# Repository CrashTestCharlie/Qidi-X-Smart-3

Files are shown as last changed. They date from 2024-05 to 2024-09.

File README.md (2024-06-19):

# Qidi X-Smart 3

- [Images](#images)
- [Mods](#mods)
- [Software/Firmware](#softwarefirmware)

------------------------------------------------------------------------

## Images

### Electronics Bay

Images:

- [Overview](images/electronics-bay.jpg)
- [Mainboard](images/mainboard-01.jpg)
- [Mainboard closeup](images/mainboard-02.jpg)
- [Mainboard ports](images/mainboard-ports.jpg)
- [Mainboard pinout](images/mainboard-pins.png)
- [Power supply](images/power-supply.jpg)
- [Power switch](images/power-switch.jpg)
- [Toolhead pinout](images/A-4.V1.2_003.PIN.pdf) (PDF)

#### Notes

Initial inspection found the USB extension cable not fully seated in the
top USB 2.0 port.

## Mods

Mods found in this repository:

- [Camera mod](./camera-mount/README.md): add a webcam
- [Config mod](./configs/README.md): fixing Qidi’s copy/paste errors and
  adding functionality.
- [Exhaust filter mod](./exhaust-filter/README.md): Add charcoal
  filtering to the exhaust fan.
- [Fan mod](./fan-mod/README.md): control the mainboard fan with
  Klipper, instead of always on.
- [Heater mod](./heater-mod/README.md): active chamber heater mod
- [Thermistor mount](./thermistor-mount/README.md): a mount for the
  thermistor used in the header mod.

## Software/Firmware

Software/Firmware versions as shipped:

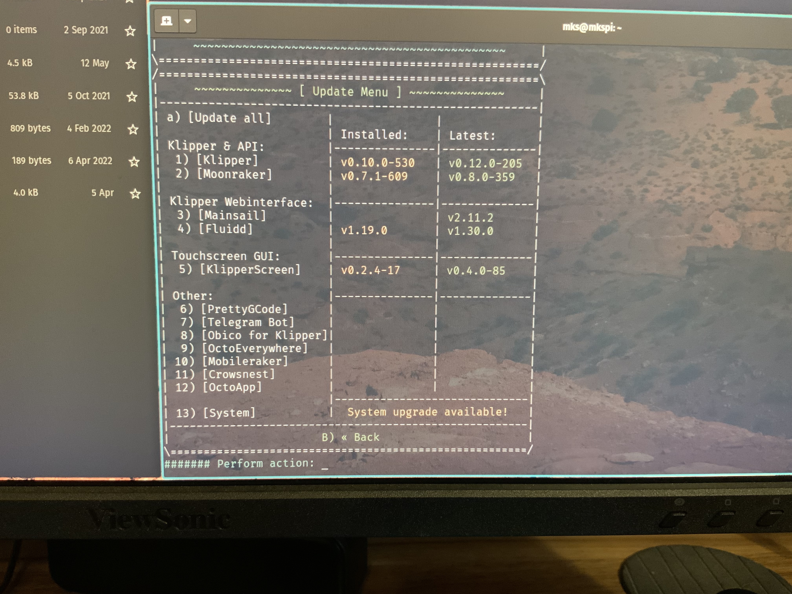
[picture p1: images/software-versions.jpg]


Default ssh login: mks/makerbase

Armbian OS info:

    mks@mkspi:~$ cat /etc/armbian-image-release
    # PLEASE DO NOT EDIT THIS FILE
    BOARD=mkspi
    BOARD_NAME="mkspi"
    BOARDFAMILY=rockchip64
    BUILD_REPOSITORY_URL=https://github.com/armbian/build.git
    BUILD_REPOSITORY_COMMIT=ed589b248-dirty
    VERSION=22.05.0-trunk
    LINUXFAMILY=rockchip64
    ARCH=arm64
    IMAGE_TYPE=user-built
    BOARD_TYPE=conf
    INITRD_ARCH=arm64
    KERNEL_IMAGE_TYPE=Image
    IMAGE_UUID=16031aaf-8c15-492e-97bf-3453cab5322c

    mks@mkspi:~$ cat /etc/armbian-release
    # PLEASE DO NOT EDIT THIS FILE
    BOARD=mkspi
    BOARD_NAME="mkspi"
    BOARDFAMILY=rockchip64
    BUILD_REPOSITORY_URL=https://github.com/armbian/build.git
    BUILD_REPOSITORY_COMMIT=ed589b248-dirty
    VERSION=22.05.0-trunk
    LINUXFAMILY=rockchip64
    ARCH=arm64
    IMAGE_TYPE=user-built
    BOARD_TYPE=conf
    INITRD_ARCH=arm64
    KERNEL_IMAGE_TYPE=Image
    BRANCH=edge

    mks@mkspi:~$ cat /etc/armbian-distribution-status
    bullseye=supported
    impish=csc
    xenial=eos
    stretch=eos
    buster=supported
    hirsute=supported
    sid=csc
    jammy=csc
    focal=supported
    bionic=csc

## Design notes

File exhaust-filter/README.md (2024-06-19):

# X-Smart 3 Exhaust Fan Filter

An activated charcoal filter for the exhaust fan. The replacement fan
mount also includes a thermistor mount for monitoring chamber
temperature.

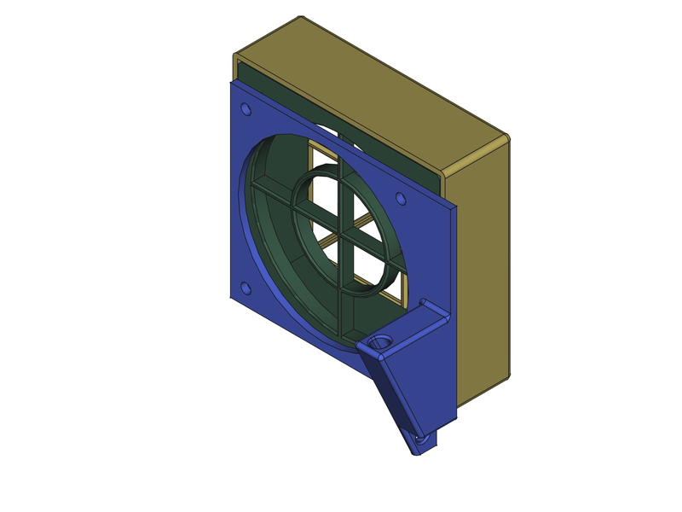
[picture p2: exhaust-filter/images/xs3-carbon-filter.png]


## Parts needed

- Printed parts from the [STLs directory](./STLs/)
- 4 M3x4x5mm heat set inserts
- 4 M3x20mm cap screws
- Activated charcoal filter media, Amazon ASIN:
  [B09F6793ST](https://a.co/d/02k9A120). This package will make 40
  filter squares.

## Instructions

1.  Install heat set inserts into the `filter-base.stl` from the flat
    side.
2.  Remove the fan from the XS3.
3.  Re-install the fan.
    1.  The `fan-mount.stl` goes between the fan and the chamber wall.
    2.  Install the `filter-base.stl` with the arrow pointing up.
4.  Using the `filter-jig.stl` cut the filter media into 60x60mm
    squares.
5.  Install one or two filter squares into the `filter-base.stl`.
6.  Slide `filter-cover.stl` onto the `filter-base.stl` from the top.
    Make sure it clicks into place.

Enjoy your filtered exhaust.

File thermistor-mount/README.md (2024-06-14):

# Thermistor Mount

This is a mount for a chamber thermistor.

## Hardware needed

- 1 thermistor
- 4 M3x20mm cap screws
- 1 printed mount

The STL can be found in this directory,
[xs3-thermistor-mount.stl](./xs3-thermistor-mount.stl). Print as
imported.

The thermistor used can be found on amazon, [3950 NTC 100K Thermistor
Sensor (5 pack)](https://a.co/d/aC1xXPI).

## Tools needed

- 2.5mm hex wrench
- JST-XH terminals and crimpers (optional)

The terminals and crimpers are only needed if shortening the thermistor
leads.

# Installation

1.  Remove the chamber exhaust fan. The fan, fan grill, and nuts will be
    reused.
2.  Install the thermistor into the mount from the bottom.
3.  Using a M3x20mm screw, line up the fan and mount and insert the
    screw into the top right mounting hole.
4.  Loop the thermistor lead through the hook on the bottom of the
    mount.
5.  Install the grill and nut on the screw, but don’t tighten.
6.  Install the other three screws.
7.  Tighten all the screws, making sure the thermistor leads are still
    captured by the mount’s hook.
8.  Adjust the thermistor so the body is above the mount.
9.  Remove the two cable clips on the rear left side of the printer.
10. Route the thermistor lead through the clips.
11. Reattach the cable clips.
12. Route the thermistor lead through the hole in the center rear of the
    chamber floor. Make sure the leads run behind the bed cable.
13. Follow the directions for the [Chamber Heater
    Mod](../heater-mod/README.md) for connection and Klipper
    integration.

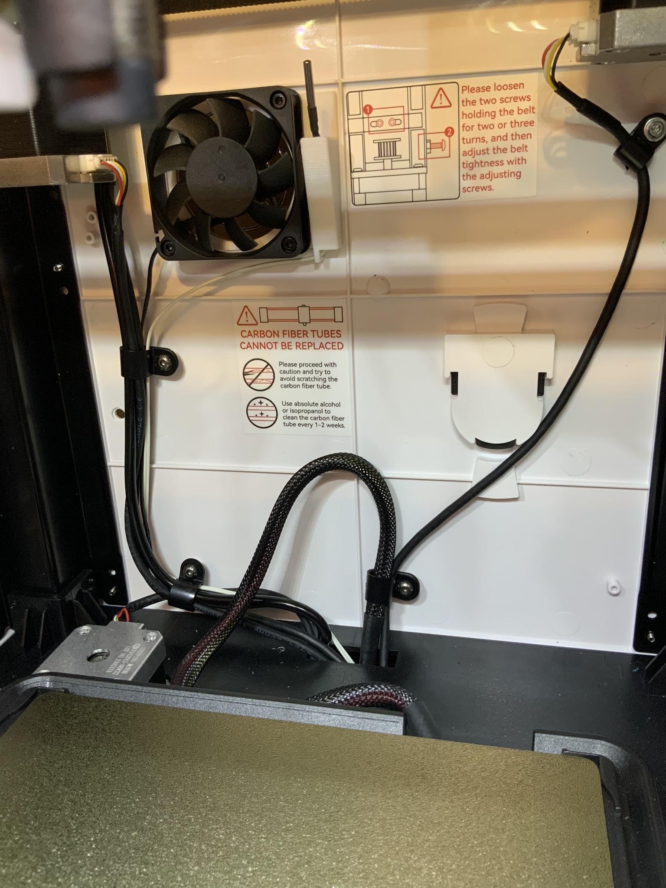
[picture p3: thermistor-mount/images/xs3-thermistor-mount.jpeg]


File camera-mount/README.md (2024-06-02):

# Camera Mount

While Qidi sells a camera, using a better camera makes for a better
result.





## The Mount

The mount is a printed base and lid that mounts on the right front
upright of the X-Smart 3 using existing mounting holes.



### Tools needed

- Heatset tool (soldering iron with heatset tips, or equivalent)
- 3mm hex wrench
- 2.5mm hex wrench
- Other screwdrivers as needed. (The only 2.5mm screws I could source
  locally were slotted drive.)

### Parts required

- Webcam module, [Innomaker 1080P USB2.0 UVC
  Camera](https://a.co/d/d5Mff7J), cable included
- The printed mount, [STL here](camera-mount.stl)
- 2x 2.5 x 4 mm heatset inserts
- 2x 3 x 6 mm heatset inserts
- 2x M3 x 8mm screws
- 2x M2.5 x 6mm screws

## Instructions

Installing the mount does involve removal of the right side plastic. Be
careful with the plastic tabs that lock it all together.

- Install the heatset inserts into the camera mount base. The M2.5
  inserts are for the front lid and the M3 inserts are for the mounting
  holes on the rear. For the lid, only two are needed, installing four
  is optional.
- Remove the six screws holding the right side cover.
- Gently pull the cover away from the housing starting at the bottom
  front.
- Remove the top black plastic ring that holds the top clear cover. Lift
  up on it starting from the front right corner and work your way
  around.
- Remove three screws that hold the front plastic to the frame near the
  front right upright.
- Gently pry the front cover away from the frame to expose the mounting
  holes.
- Position the mount so the top of the mount (with the cable exit) is in
  the corner of the front right upright and level with the top of the
  upright.
- Install the M3 screws to secure the mount to the upright.
- Lay the printer on its side and remove the bottom cover.
- Route the camera USB cable from the electronics bay up the right front
  upright. Follow the screen cable through the hole in the bottom
  corner. Make sure the camera connector reaches the top of the upright
  with some slack.
- Connect the USB cable to an open port on the mainboard. Secure the
  extra in the same area as the external port cable.
- Re-install the bottom cover and set the printer upright.
- Connect the cable to the camera module.
- Position the camera module into the mount base with the connector
  aligned with the cutout.
- Attach the camera mount lid with two M2.5 screws.
- Reattach the front cover with three screws.
- Reinstall the top ring.
- Reinstall the right side cover with six screws.

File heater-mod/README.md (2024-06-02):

# Chamber Heater Mod

While Qidi states that the **X Smart 3** _can_ print ABS/ASA, the stock printer _can not_ realistically reach an adequate chamber temperature (50℃) with just the hotend and bed heaters. Thankfully the controller board has an adequate number of unused connections to add a dedicated chamber heater.

The parts I used are:

* [10A DC to AC SSR](https://www.amazon.com/gp/product/B09NPKGXMG)
* [350w 110v PTC Heater](https://www.amazon.com/gp/product/B07NY18B6Z)
* [3950 Thermistor](https://www.amazon.com/gp/product/B099K2DKXJ)

## Wiring

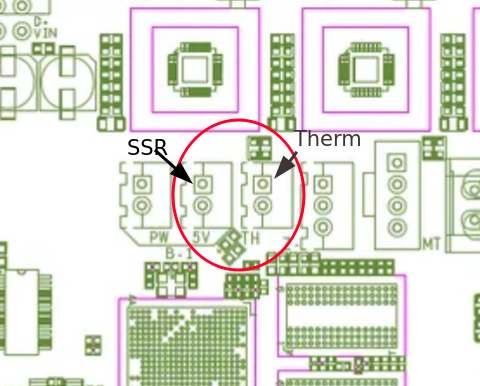
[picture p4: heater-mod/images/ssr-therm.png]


Connect your chamber thermistor to the connector marked **TH** as shown above.

The connector to its left (labeled **5v**) can be used as the control pins for the **SSR**.

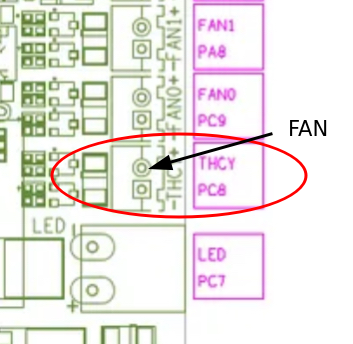
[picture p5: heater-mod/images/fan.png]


The PTC heater's fan can be controlled with the port on the right of the board labeled **THCY**.

## Macros and Config

Copy the [heater.cfg](heater.cfg) to your printer and be sure to include it near the bottom of your `printer.cfg`.

With this configuration you can simply check the box in your slicer for chamber temp (as shown below in Orca Slicer's filament settings)



When activated, the generated g-code _should_ heat the chamber to the desired temperature at the start of the print.

Additionally, the delayed g-codes will monitor for the end of the print and engage the printer's exhaust fan to cool the chamber after the print.

### PID Calibration

Once everything is wired and the configuration put in place, I suggest PID tuning the heater with the following:

```
PID_CALIBRATE HEATER=chamber TARGET=60
```

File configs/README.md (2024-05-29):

# Sensible Configuration

The file `./printer.cfg.orig` is the `printer.cfg` that originally
shipped with the X-Smart 3. It’s added here for reference purposes.

## Configuration

To help clean up and organize the configuration, the original
`printer.cfg` has been split up an organized into it’s own directory.

The file tree looks like this:

    .
    ├── printer.cfg
    ├── printer.cfg.orig
    ├── README.md
    └── x-smart-3
        ├── 00-hardware.cfg
        ├── 01-steppers.cfg
        ├── control.cfg
        ├── fans.cfg
        ├── macros.cfg
        ├── pins.cfg
        └── temps.cfg

The `PRINT_START` type macros are found in `control.cfg` which contains
the macros that will most likely need personalization.

## Changes

These config files contain changes for the mods in this repository.
Changes include:

- Mainboard fan mod
- Fan renaming
- Set fans to 100% on MCU error
- Activate temperature sensor on the Pi
- Macro updates

## Config Installation

### From a remote computer

First clone this repository to your computer and make sure you can
access the X-Smart 3 via `ssh`.

#### Backup

Before using these configs, you should backup your original
`printer.cfg`. This only needs to be done once and your original file
will be in the X-Smart 3’s home directory named `printer.cfg.orig`:

    ssh mks@mkspi.local "mv klipper_config/printer.cfg printer.cfg.orig"

#### Installation

To easily install the configs, use `rsync`. From inside the `configs`
directory, run:

    rsync -aRv printer.cfg x-smart-3/ mks@mkspi.local:klipper_config

### From the X-Smart 3

If you have cloned this repository to the X-Smart 3, use these commands
to install the new configs.

#### Backup

Before using these configs, you should backup your original
`printer.cfg`. This only needs to be once and your original file will be
found in the home directory named `printer.cfg.orig`:

    mv klipper_config/printer.cfg ./printer.cfg.orig

#### Installation

From within the `configs/` directory of this repository, copy the
configs to the correct location:

    cp -rt /tmp/klipper_config/ printer.cfg x-smart-3/

#### Finishing up

Now, from the web interface, verify that the new configs are in place,
and restart Klipper to see the changes.

## Notes

Because the fans names are hardwired into the display screen firmware,
using these configs will make the `fan1` and `fan3` screen buttons
inoperative.

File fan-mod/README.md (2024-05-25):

# Mainboard Fan Mod

The mainboard/stepper driver cooling fan runs whenever the printer’s
power is on. This is an annoying 30x10mm fan that makes a high-pitched
hum. The fix is to move the fan’s plug from an always-on socket to one
controlled by Klipper.

This mod is inspired by the Nero3D livestream found here:
https://www.youtube.com/watch?v=ojxxo1QuvFE

In that video, he moves the fan plug to an empty blue socket (at the
11:00 mark). With currently shipping versions, the blue socket is
occupied by the chamber fan. This means a slightly different approach
must be taken.

## Pin and Fan Names

In the default Fluidd interface, the fans are identified as:

- Fan0 on pin (?), this is also the part cooling fan on the extruder.
  The Fan0 slider in the interface will track the level of the part fan
  slider, but can be manually controlled independently of the part fan
  slider.
- Fan2 on pin PA8/FAN0, this is the mainboard fan that ships plugged
  into constant power. The Fluidd slider has no effect.
- Fan3 on pin PC9/FAN1, this is the chamber fan that runs according to
  slicer settings. It is normally off.

After the fan mod, The Fan2 slider will disappear, and a new entry,
`Controller Fan` will be in the list with the hotend fans. It’ll have
changed from a slider to a status indicator.

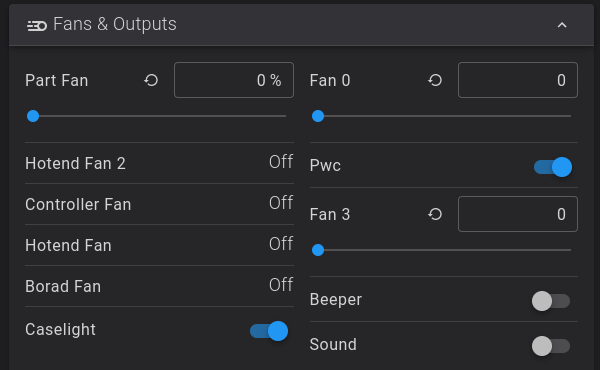
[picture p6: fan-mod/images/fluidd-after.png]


## The Fix

This mod has two parts. It’s best to do the hardware mod first, so that
the printer can be reassembled before making the software changes.

### Hardware

1.  Unplug the printer.
2.  With the printer on its left side, remove the electronics bay cover.
3.  Verify your board matches the [pinout
    diagram](../images/mainboard-pins.jpg).
4.  The fan sockets will be on the bottom edge of the mainboard. Remove
    the white plug in the VIN0 (white) socket, and insert it into the
    FAN1 (green) socket.
5.  Replace the electronics bay cover.
6.  Set the printer upright an power it on.

Wiring before:

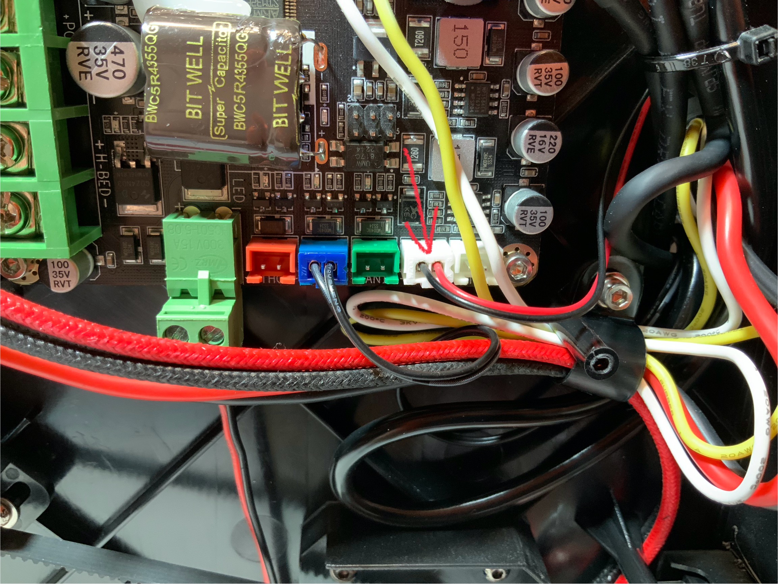
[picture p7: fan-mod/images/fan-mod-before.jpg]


Wiring after:

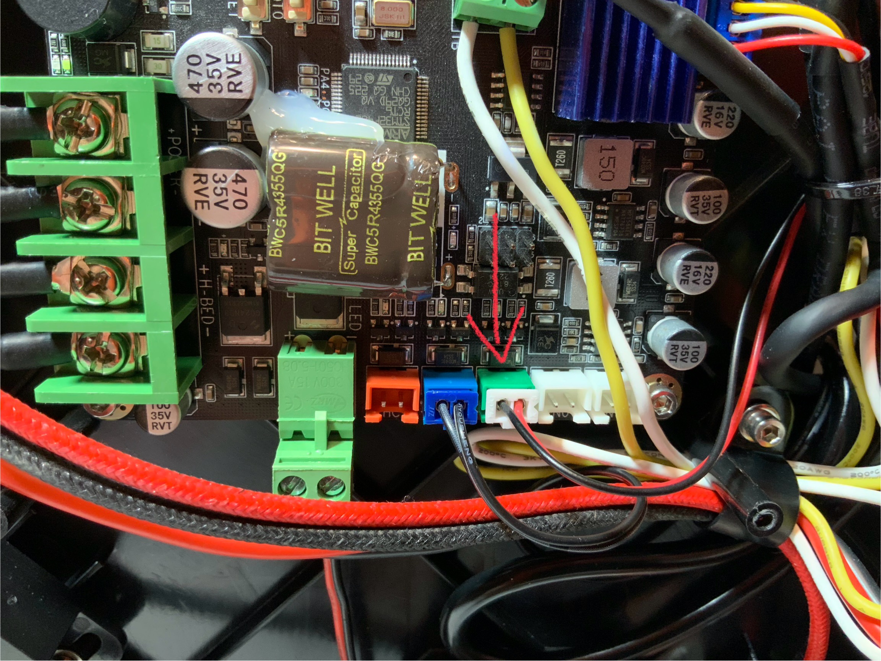
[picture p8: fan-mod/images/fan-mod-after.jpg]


### Software

1.  Verify `printer.cfg` contains the following code block:

<!-- -->

    ##主板上大涡轮风扇
    [output_pin fan2]
    pin: PA8
    pwm: True
    cycle_time: 0.0100
    hardware_pwm: false
    value: 0.00
    scale: 255
    shutdown_value: 0.0

2.  Comment out that code block, and add this code block:

<!-- -->

    [controller_fan controller_fan]
    pin: PA8
    kick_start_time: 0.5

3.  Click the `Save & Restart` button in the top bar, then go to the
    home screen and verify the mod.
4.  Using the interface buttons, home an axis to activate the stepper
    motors. Watch that the `Controller Fan` status changes from `Off` to
    `On`.

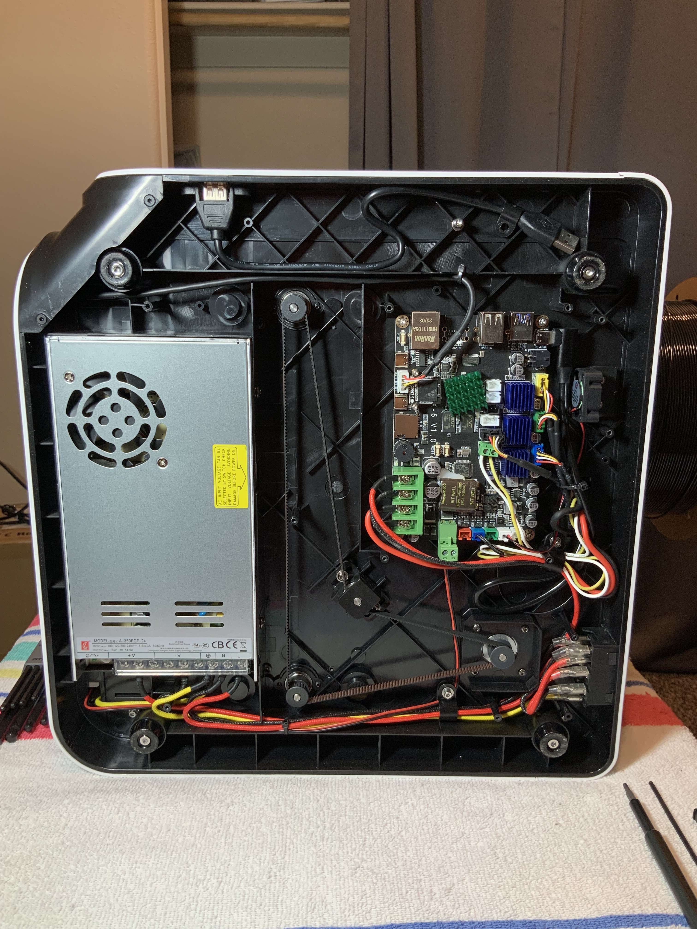
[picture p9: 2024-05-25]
images/electronics-bay.jpg

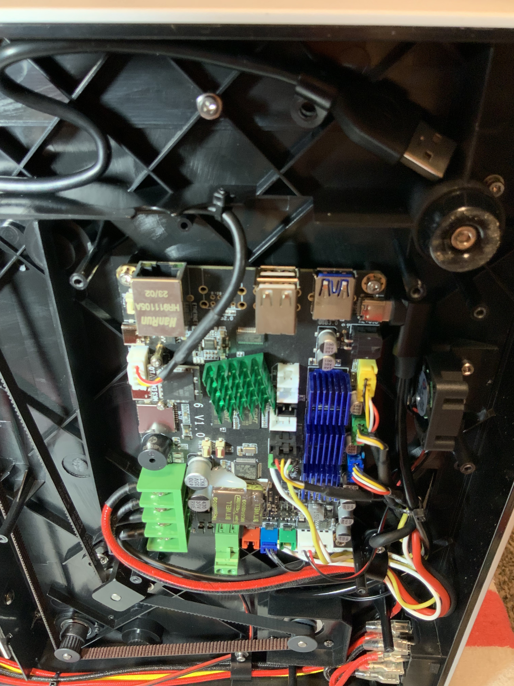
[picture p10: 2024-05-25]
images/mainboard-ports.jpg

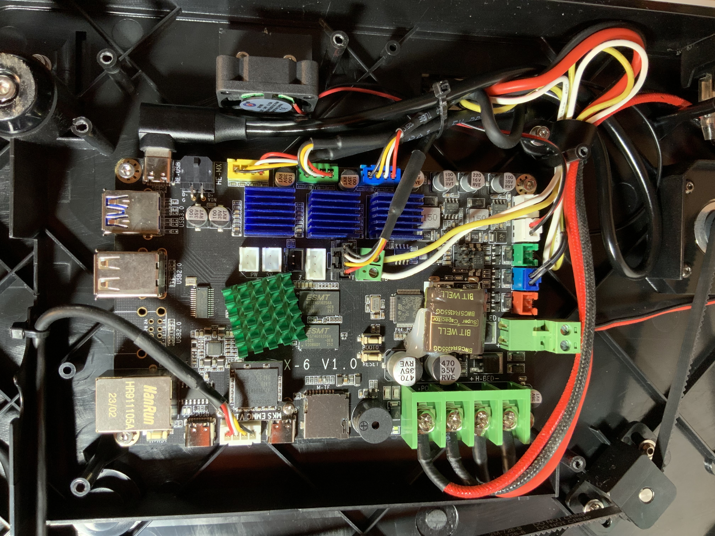
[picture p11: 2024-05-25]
images/mainboard-01.jpg

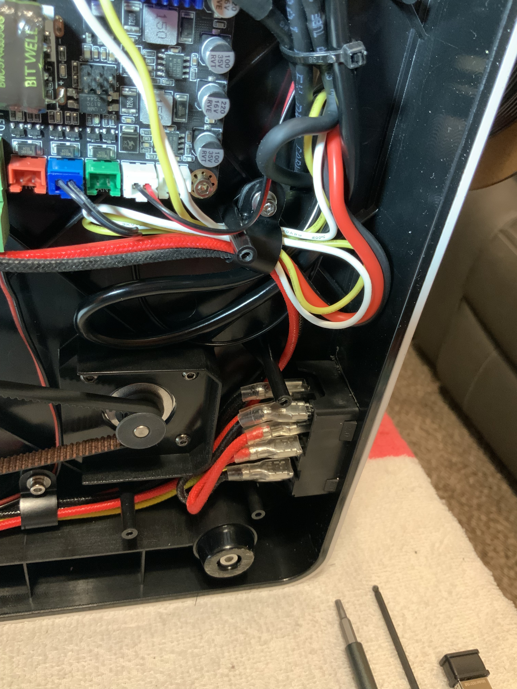
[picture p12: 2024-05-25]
images/power-switch.jpg

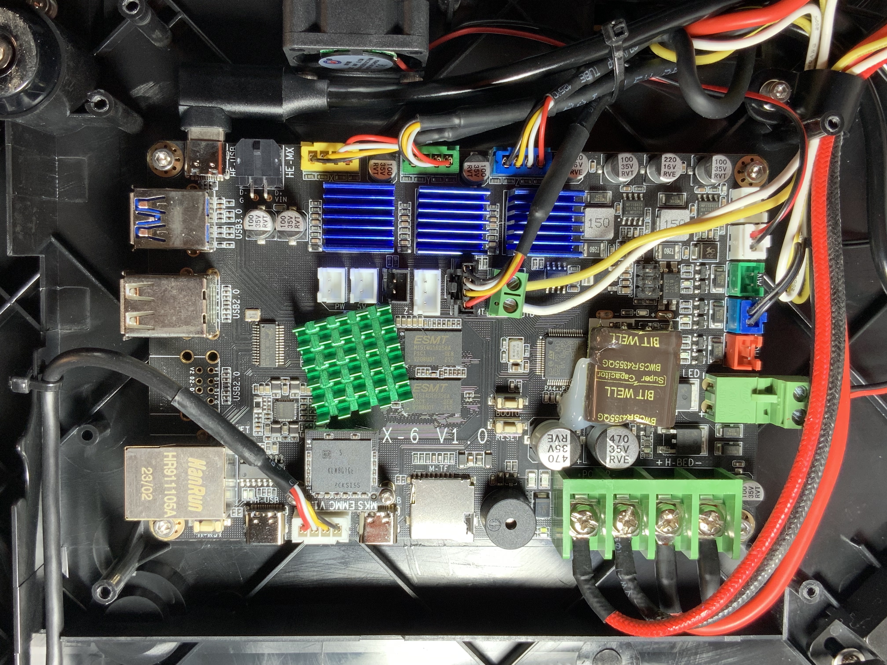
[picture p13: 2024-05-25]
images/mainboard-02.jpg

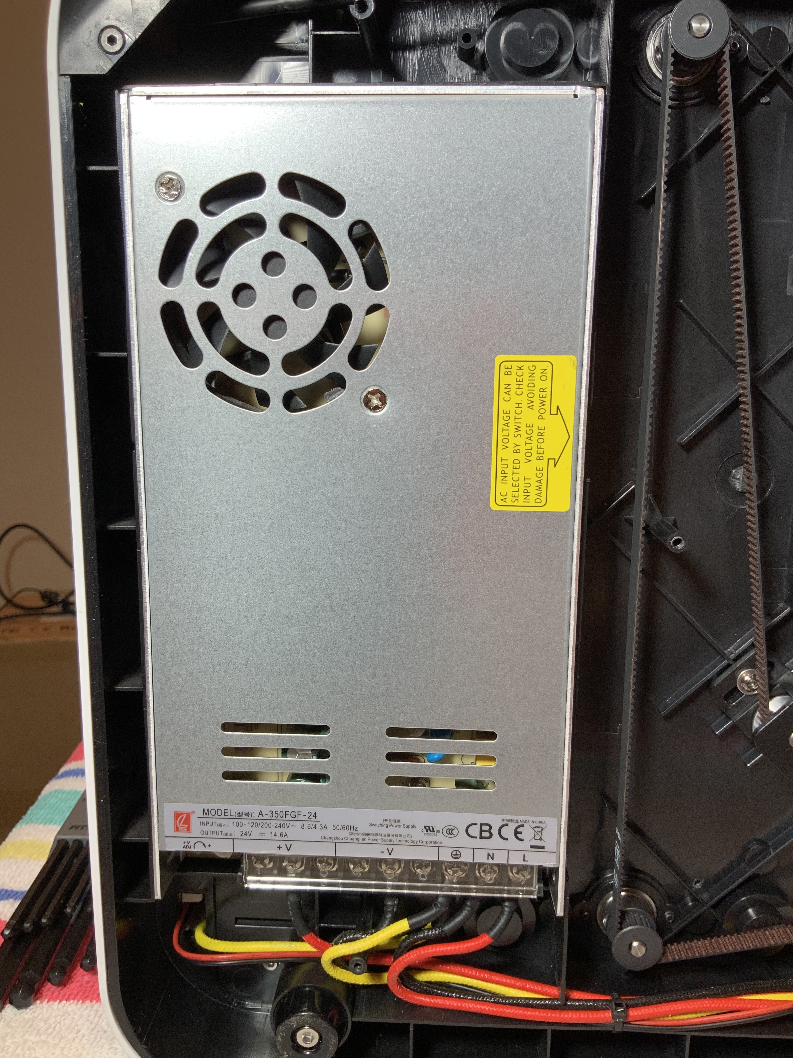
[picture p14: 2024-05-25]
images/power-supply.jpg

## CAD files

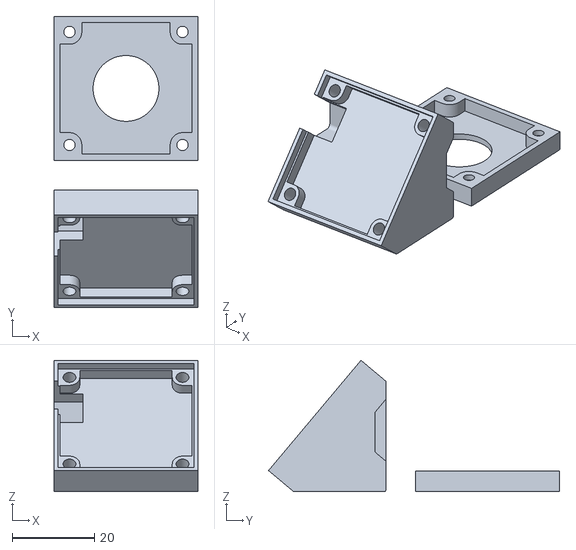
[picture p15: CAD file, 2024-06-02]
camera-mount/camera-mount.stl
35.0 x 70.8 x 32.0

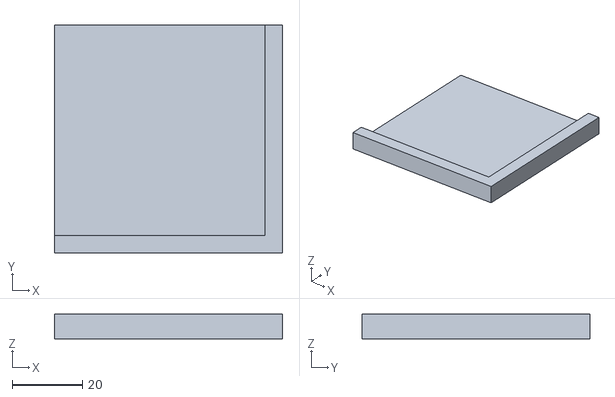
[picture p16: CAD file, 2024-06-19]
exhaust-filter/STLs/filter-jig.stl
65.0 x 65.0 x 7.00

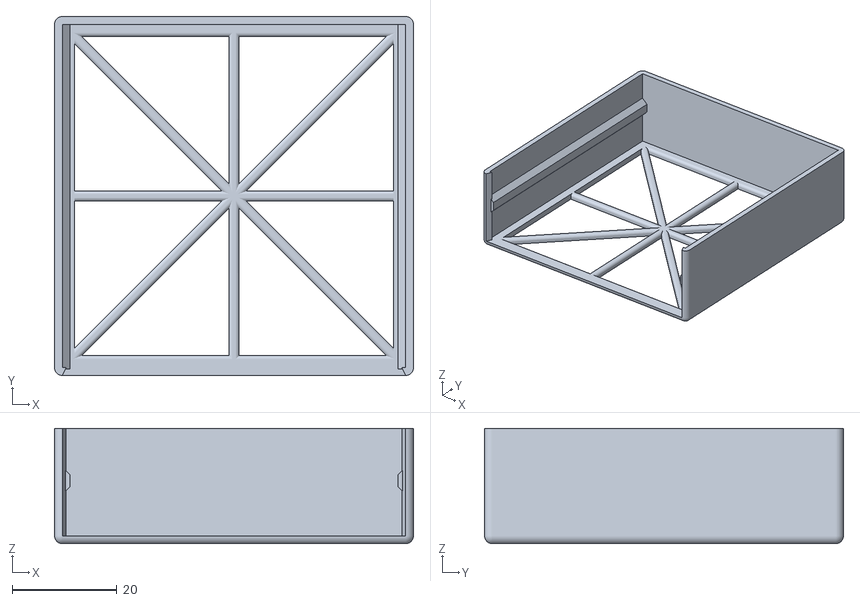
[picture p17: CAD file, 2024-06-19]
exhaust-filter/STLs/filter-cover.stl
68.5 x 68.5 x 22.0

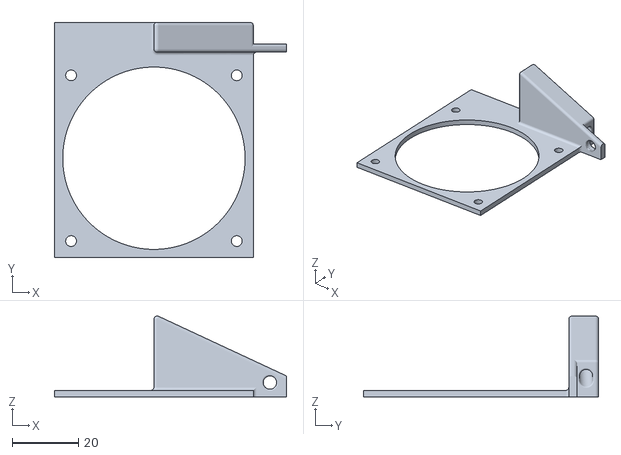
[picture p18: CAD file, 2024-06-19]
exhaust-filter/STLs/fan-mount.stl
70.0 x 71.0 x 24.4

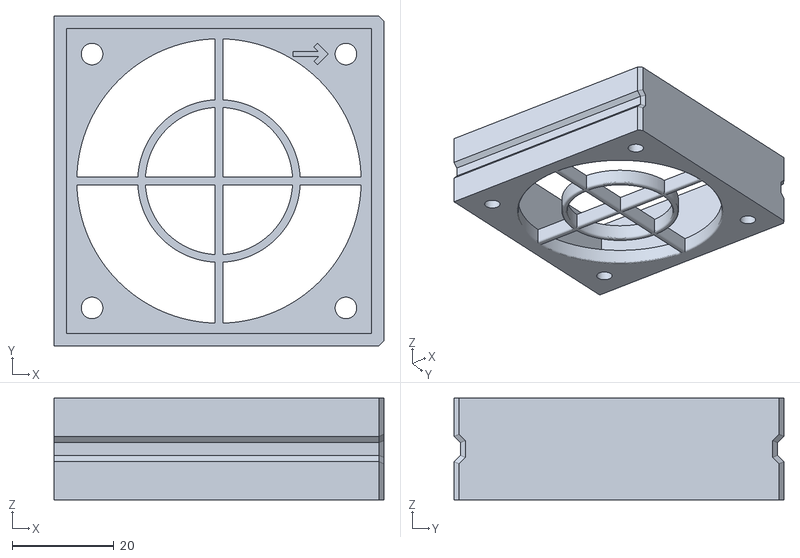
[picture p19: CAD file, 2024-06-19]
exhaust-filter/STLs/filter-base.stl
65.0 x 65.0 x 20.0

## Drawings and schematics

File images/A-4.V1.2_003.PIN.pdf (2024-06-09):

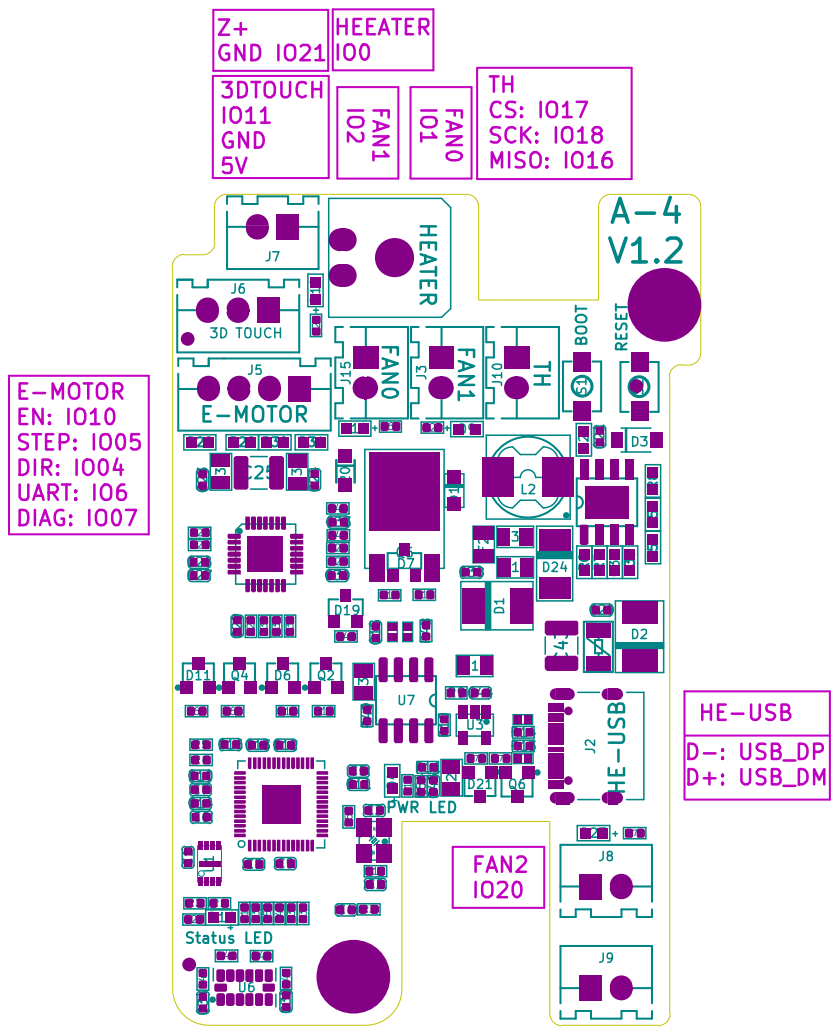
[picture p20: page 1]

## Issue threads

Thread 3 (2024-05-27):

M106 macro won't recognize new fan definintons

CrashTestCharlie, 2024-05-27:
After moving the macros from the original `printer.cfg`, the M106 macro was flagged as a duplicate and cause a Klipper error. Commenting out the M106 block fixed it and allowed Klipper to restart.

Looking at the macro, it's setup to control the various fans using `SET_PIN` commands. With the reorganized configs, only the part fan is controllable from via the built in M106 gcode, and specifying a fan with the `P` parameter is not interpreted correctly and defaults to the part fat.

The problem is that Orca slicer uses `M106 P3` to set the exhaust fan speed (filament settings/cooling), and this will instead change the part fan speed.

The M106 macro needs updating to handle this.

Side note, Orca uses `P2` to refer to an aux cooling fan, and it also wouldn't work, if the XS3 had one.

CrashTestCharlie, 2024-05-27:
This also affects fan shutdown, as `M107` is depreciated. The recommended replacement is `M106 S0`, which only works with the part fan.

Closed 2024-05-29.

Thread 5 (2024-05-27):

PRINT_START macro is blank

CrashTestCharlie, 2024-05-27:
It should have one.

CrashTestCharlie, 2024-06-09:
Closed by  #23

Closed 2024-06-09.

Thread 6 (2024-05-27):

PRINT_END macro uses M106 Px gcodes

CrashTestCharlie, 2024-05-27:
Currently the M106 gcode will not control fans other than the part fan due to implementing correct fan configs.

Related to: #3

Closed 2024-05-30.

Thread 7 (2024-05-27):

CPU temperature high-ish

CrashTestCharlie, 2024-05-27:
With the Pi temp sensor enable, it appears the Pi is idling around 72C. This is close enough to the shutdown limit of 85C. Especially if high-temp materials are being used.

The current mainboard fan mostly only cools the stepper drivers. So a dedicated CPU cooling solution might be needed.

CrashTestCharlie, 2024-06-11:
Closed by #25

Closed 2024-06-11.

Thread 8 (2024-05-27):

Power supply fan is loud

CrashTestCharlie, 2024-05-27:
Maybe it can be replaced. Would need to know the size and maybe print a cover that allows more air flow.

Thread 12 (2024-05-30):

Fix Orca Slicer fan numbering

CrashTestCharlie, 2024-05-30:
Orca fan numbers from test gcode:

- Part fan: blank (`M106 S122` for example)
- Exhaust fan: P3 (`M106 P3 S255` for example)
- Aux part fan: P2 (`M106 P2 S102` for example)

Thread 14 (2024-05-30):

Update documentation for configs

CrashTestCharlie, 2024-05-30:
Things to consider:

- Fan names
- start/end macros

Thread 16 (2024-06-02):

Remove chamber heater code from configs dir

CrashTestCharlie, 2024-06-02:
With the chamber heater mod merged, defer to it's config, and make sure no chamber heater references are in the configs.

Also add an instruction to add the chamber config into the `x-smart-3` dir if using the updated configs.

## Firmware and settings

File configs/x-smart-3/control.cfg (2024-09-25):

[gcode_macro START_PRINT]
# Orca Slicer Machine Start G-code:
# START_PRINT EXTRUDER_TEMP=[nozzle_temperature_initial_layer] BED_TEMP=[bed_temperature_initial_layer_single]
# Note about SOAK_TIME:
# By default it is set for 2 minutes. By creating a new printer profile and
# adding SOAK_TIME=<minutes> to the PRINT_START macro you can choose your heat
# soak time when slicing.
description: Initial print setup
gcode:
    # set variables
    {% set target_bed = params.BED_TEMP|int %}
    {% set target_extruder = params.EXTRUDER_TEMP|int %}
    {% set soak_minutes = params.SOAK_TIME | default(2) | int %}
    {% set x_wait = printer.toolhead.axis_maximum.x|float / 2 %}
    {% set y_wait = printer.toolhead.axis_maximum.y|float / 2 %}

    # start bed heating
    M140 S{target_bed}

    # home and center toolhead
    RESPOND PREFIX="Starting print:" MSG="printhead homing..."
    G28
    G90
    G0 X{x_wait} Y{y_wait} Z5 F5000

    # wait for bed temp, then soak
    RESPOND PREFIX="Starting print:" MSG="bed heating..."
    M190 S{target_bed}
    {% for m in range(soak_minutes) %}
        {% if m == 1 %}
            # preheat nozzle
            M104 S150
        {% endif %}
       RESPOND PREFIX="Starting print:" MSG="heat soaking: {soak_minutes - m}m left..."
       G4 P{1000*60} #one minute
    {% endfor %}

    # adaptive bed mesh
    RESPOND PREFIX="Starting print:" MSG="creating bed mesh..."
    BED_MESH_CLEAR
    BED_MESH_CALIBRATE

    # wait for nozzle temp
    RESPOND PREFIX="Starting print:" MSG="nozzle heating..."
    M109 S{target_extruder}

    # adaptive purge
    LINE_PURGE

[gcode_macro PRINT_END]
# This is a dummy macro because the printer calls `PRINT_END` automatically at
# the end of a print for no reason other than "fuck you."
description: DO NOT USE
gcode:
    # intentionally blank

[gcode_macro END_PRINT]
# Slicer Machine End G-code:
# END_PRINT FAN_TIMEOUT=60
# Note about FAN_TIMEOUT:
# By defualt it is set for 60 seconds, after which the part fan is turned off
# (it is activated when this macro is called to help cool the extruder). Also
# if the exhaust fan is running, it will be turned off after FAN_TIMEOUT * 5
# seconds.
description: After print clean up
gcode:
    # set variables
    {% set fan_timeout = params.FAN_TIMEOUT | default(60) | int %}
    {% set extruder_temp = printer.extruder.temperature %}
    {% set extruder_min_temp = printer.configfile.settings.extruder.min_extrude_temp %}
    {% set x_center = printer.toolhead.axis_maximum.x | float / 2 %}
    {% set y_center = printer.toolhead.axis_maximum.y | float / 2 %}
    {% set z_loc = printer.gcode_move.position.z %}
    {% set z_end = printer.toolhead.axis_maximum.z - 5 %}

    # retract if hot
    {% if extruder_temp > extruder_min_temp %}
        RESPOND PREFIX="Ending:" MSG="retracting filament"
        M83
        G0 E-1.5 F20
    {% endif %}

    # heaters off
    RESPOND PREFIX="Ending:" MSG="heaters off"
    TURN_OFF_HEATERS

    # lower bed if not low
    {% if z_loc < z_end %}
        RESPOND PREFIX="Ending:" MSG="lowering bed"
        G90
        G0 Z{z_end} F1000
    {% endif %}

    # park toolhead
    RESPOND PREFIX="Ending:" MSG="parking toolhead"
    G90
    G0 X{x_center} Y{y_center} F5000
    # stop motors
    M84

    # clear pause state in case of cancel after pause
    CLEAR_PAUSE
    # set timeout back to configured value
    SET_IDLE_TIMEOUT TIMEOUT={printer.configfile.settings.idle_timeout.timeout}

    # use part fan for cooldown
    M106
    # delay fan shutdown
    UPDATE_DELAYED_GCODE ID=DELAYED_PART_FAN_SHUTDOWN DURATION={fan_timeout}
    UPDATE_DELAYED_GCODE ID=DELAYED_EXHAUST_FAN_SHUTDOWN DURATION={fan_timeout * 5}

    # reset speed and extruder overrides
    M220 S100
    M221 S100

[delayed_gcode DELAYED_PART_FAN_SHUTDOWN]
gcode:
    M106 S0

[delayed_gcode DELAYED_EXHAUST_FAN_SHUTDOWN]
gcode:
    SET_FAN_SPEED FAN=exhaust_fan SPEED=0

[gcode_macro CANCEL_PRINT]
rename_existing: BASE_CANCEL_PRINT
gcode:
    SDCARD_RESET_FILE
    END_PRINT
    BASE_CANCEL_PRINT

[gcode_macro PAUSE]
rename_existing: BASE_PAUSE
gcode:
    # Parameters
    ; z hop amount
    {% set z = params.Z|default(50)|int %}

    {% if printer['pause_resume'].is_paused|int == 0 %}
        ; set z hop variable for reference in resume macro
        SET_GCODE_VARIABLE MACRO=RESUME VARIABLE=zhop VALUE={z}
        ; set hotend temp variable for reference in resume macro
        SET_GCODE_VARIABLE MACRO=RESUME VARIABLE=etemp VALUE={printer['extruder'].target}
        ; disable filament sensor
#       SET_FILAMENT_SENSOR SENSOR=fila ENABLE=0
        ; save current print position for resume
        SAVE_GCODE_STATE NAME=PAUSE
        ; pause print
        BASE_PAUSE
        ; check that zhop doesn't exceed z max
        {% if (printer.gcode_move.position.z + z) < printer.toolhead.axis_maximum.z %}
            ; relative positioning
            G91
            ; raise Z up by z hop amount
            G1 Z{z} F900
        {% else %}
            ; if z max is exceeded, show message and set zhop value for resume to 0
#           { action_respond_info("Pause zhop exceeds maximum Z height.") }
            SET_GCODE_VARIABLE MACRO=RESUME VARIABLE=zhop VALUE=0
        {% endif %}
        SAVE_GCODE_STATE NAME=PAUSEPARK2
        ; absolute positioning
        G90
        ; park toolhead at front center
        G1 X{printer.toolhead.axis_maximum.x/2} Y{printer.toolhead.axis_maximum.y} F6000
        ; save parked position in case toolhead is moved during the pause
        ; (otherwise the return zhop can error)
        SAVE_GCODE_STATE NAME=PAUSEPARK
        ; turn off hotend
        M104 S0
        ; set timeout to 12 hours
        SET_IDLE_TIMEOUT TIMEOUT=86400
        SET_STEPPER_ENABLE STEPPER=extruder enable=0
    {% endif %}

[gcode_macro RESUME]
rename_existing: BASE_RESUME
variable_zhop: 0
variable_etemp: 0
gcode:
    # Parameters
    ; hotend prime amount (in mm)
    {% set e = params.E|default(2.5)|int %}

    {% if printer['pause_resume'].is_paused|int == 1 %}
         ; enable filament sensor
#        SET_FILAMENT_SENSOR SENSOR=fila ENABLE=1
        ; reset LCD color
        #INITIAL_RGB
        ; set timeout back to configured value
        SET_IDLE_TIMEOUT TIMEOUT={printer.configfile.settings.idle_timeout.timeout}
        {% if etemp > 0 %}
            ; wait for hotend to heat back up
            M109 S{etemp|int}
        {% endif %}
        ; go back to parked position in case toolhead was moved during pause
        ; (otherwise the return zhop can error)
        RESTORE_GCODE_STATE NAME=PAUSEPARK MOVE=1 MOVE_SPEED=100
        ; relative positioning
        G91
        ; relative extruder positioning
        M83
        {% if printer[printer.toolhead.extruder].temperature >= printer.configfile.settings.extruder.min_extrude_temp %}
            ; prime nozzle by E, lower Z back down
            G1  E{e} F900
#        {% else %}
             ; lower Z back down without priming (just in case we are testing the macro with cold hotend)
#            G1 Z{zhop * -1} F900
        {% endif %}
        RESTORE_GCODE_STATE NAME=PAUSEPARK2 MOVE=1 MOVE_SPEED=100
        ; restore position
        RESTORE_GCODE_STATE NAME=PAUSE MOVE=1 MOVE_SPEED=60
        ; resume print
        BASE_RESUME
    {% endif %}
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

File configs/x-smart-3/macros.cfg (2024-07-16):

## ===========================================================================
# Named macros
##

[gcode_macro beep_on]
Description: Enable sound
gcode:
    SET_PIN PIN=sound VALUE=1

[gcode_macro beep_off]
Description: Disable sound
gcode:
    SET_PIN PIN=sound VALUE=0

[gcode_macro BEEP]
Description: Activate the beeper
# Parameters
#   In   Iterations (number of times to beep).
#   DURnnn Duration/wait of each beep in ms. Default 100ms.
gcode:
    {% set count = params.I | default(1) | int %}
    {% set length = params.DUR | default(100) | int %}

    {% if printer["output_pin sound"].value|int == 1 %}
        {% for _ in range(count) %}
            SET_PIN PIN=beeper VALUE=1
            G4 P{length}
            SET_PIN PIN=beeper VALUE=0
            G4 P{length}
        {% endfor %}
    {% endif %}

[delayed_gcode KINEMATIC_POSITION]
initial_duration:0.2
gcode:
    SET_KINEMATIC_POSITION X=150
    SET_KINEMATIC_POSITION Y=150
    SET_KINEMATIC_POSITION Z=150
    SET_FILAMENT_SENSOR SENSOR=fila ENABLE=0

[gcode_macro SHAPER_CALIBRATE]
rename_existing: RESHAPER_CALIBRATE
gcode:
    RESHAPER_CALIBRATE FREQ_START=30 FREQ_END=150
    SAVE_CONFIG

## ===========================================================================
# G macros
##

[gcode_macro G29]
variable_k:1
gcode:
    {% if k|int==1 %}
        BED_MESH_CLEAR      #清除调平数据/Clear the leveling data
        # G28
        BED_MESH_CALIBRATE PROFILE=kamp  #自动调平/Auto-leveling 
    {% endif %}

[gcode_macro G30]
gcode:
    BED_MESH_CLEAR      #清除调平数据/Clear the leveling data
    # G28
    BED_MESH_CALIBRATE mesh_min=10,10  mesh_max=170,170  METHOD=manual #手动动调平/Auto-leveling 

[gcode_macro G31]
gcode:
    SET_GCODE_VARIABLE MACRO=G29 VARIABLE=k VALUE=1

[gcode_macro G32]
gcode:
    SET_GCODE_VARIABLE MACRO=G29 VARIABLE=k VALUE=0

## ===========================================================================
# M macros 0-99
##

[gcode_macro M0]
gcode:
    PAUSE

[gcode_macro M25]
rename_existing: M25.1
gcode:
    PAUSE

[gcode_macro M84]
rename_existing:M84.1
gcode:
    SET_STEPPER_ENABLE STEPPER=stepper_x enable=0
    SET_STEPPER_ENABLE STEPPER=stepper_y enable=0
    SET_STEPPER_ENABLE STEPPER=stepper_z enable=0
    SET_STEPPER_ENABLE STEPPER=extruder enable=0
    SET_KINEMATIC_POSITION

## ===========================================================================
# M macros 100-199
##

[gcode_macro M141]
Description: Set chamber heater temperature
# Parameters
#   Snnn Active/Target temperature
gcode:
    {% set temp = params.S | default(0) %}
    {% if printer['heater chamber'] is defined %}
        SET_HEATER_TEMPERATURE HEATER=chamber TARGET={temp}
    {% endif %}

[gcode_macro M106]
description: Set fan speeds
# Parameters
#   Pn  Fan numbers used by Orca Slicer
#       P0 Part fan
#       P2 Bento Mini filter fan
#       P3 Exhaust fan
#   Snnn Fan speed (0-255)
rename_existing: M106.1
gcode:
    # edit fan names/index here:
    {% set fan_names = {2: 'filter_fan', 3: 'exhaust_fan'} %}

    {% set raw_speed = params.S | default(255) | int %}
    {% set speed = (raw_speed / 255) | float %}
    {% set fan_idx = params.P | default(0) | int %}

    {% if fan_idx == 0 %}
        M106.1 S{raw_speed}
    {% elif fan_idx in fan_names %}
        {% set fan = fan_names[fan_idx] %}
        {% if printer['fan_generic ' + fan] is defined %}
            SET_FAN_SPEED FAN={fan} SPEED={speed}
        {% endif %}
    {% endif %}

[gcode_macro M107]
description: Stop all fans
rename_existing:M107.1
gcode:
    {% for fan in range(4) %} # 0-3
        M106 P{fan} S0
    {% endfor %}

## ===========================================================================
# M macros 200-299
##

[gcode_macro M204]
rename_existing: M204.1
gcode:
    {% if params.S is defined %}
        {% set s = params.S|float %}
    {% endif %}
    {% if params.P is defined %}
    {% if params.T is defined %}
        {% set s = [params.P|float ,params.T|float] | min %}
    {% endif %}
    {% endif %}

    SET_VELOCITY_LIMIT ACCEL={s}
    SET_VELOCITY_LIMIT ACCEL_TO_DECEL={s/2}

[gcode_macro M290]
gcode:
   SET_GCODE_OFFSET Z_ADJUST={params.Z}

## ===========================================================================
# M macros 300-399
##

[gcode_macro M303]
description: PID calibrate, H0: extruder, H1: bed
# Parameters
#   Hn  Heater
#       H0 extruder
#       H1 bed
#       H2 chamber
#   Snn Temperature
gcode:
    {% set heater = params.H | default(0) | int %}
    {% set temp = params.S | default(200) | int %}

    {% if heater == 0 %}
        PID_CALIBRATE HEATER=extruder TARGET={temp}
    {% endif %}

    {% if heater == 1 %}
        PID_CALIBRATE HEATER=heater_bed TARGET={temp}
    {% endif %}

    {% if heater == 2 %}
        PID_CALIBRATE HEATER=chamber_heater TARGET={temp}
    {% endif %}

## ===========================================================================
# M macros 400+
##

[gcode_macro M603]
description: filament unload
gcode:
    G92 E0
    G0  E15 F400
    G4  P1000
    G92 E0
    G1  E-80 F800

[gcode_macro M604]
description: filament load
gcode:
    M83
    G1  E80 F400

[gcode_macro M900]
gcode:
    {% if params.K is defined %}
          SET_PRESSURE_ADVANCE ADVANCE={params.K}
    {% endif %}
    {% if params.T is defined %}
       SET_PRESSURE_ADVANCE SMOOTH_TIME={params.T}
    {% endif %}

[gcode_macro M901]
gcode:
#    M104 S140
    G28
    SHAPER_CALIBRATE
    SAVE_CONFIG

[gcode_macro M1029]
gcode:
#    X_TWIST_PROFILE_LOAD NAME=default
#    X_TWIST_COMPENSATE_MESH MESH_NAME=default COMPENSATION_NAME=default
#    SAVE_CONFIG

[gcode_macro M4029]
gcode:
    BED_MESH_CLEAR
    G91
    G1 Z10 F600
    G90
    G28
    G1 X{printer.toolhead.axis_maximum.x/2 - printer.probe["x_offset"]} Y{printer.toolhead.axis_maximum.y/2 - printer.probe["y_offset"]} F7800
    G1 Z15 F600
    ABORT
    PROBE_CALIBRATE
    ABORT
    G0 Z0
#    TESTZ Z=-3.0

[gcode_macro M8029]
gcode:
     {% if params.D is defined %}
       {% if (params.D|int)==1 %}
        SET_FILAMENT_SENSOR SENSOR=fila  ENABLE=1
       {% endif %}
       {% if (params.D|int)==0 %}
        SET_FILAMENT_SENSOR SENSOR=fila  ENABLE=0
       {% endif %}
     {% endif %}

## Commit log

2024-05-25 Add fan mod text/pic
2024-05-29 Reorganize configs (#4)
    Split the original `printer.cfg` into sub-files for easier organization.
    Also reconfigure the fans to use the appropriate sections and eliminate
    redundancies caused by sloppy copy/pastes from the factory.
    This includes rewriting the M106 and M107 macros.
    Closes #1
    Closes #3
    ---------
    [00-hardware.cfg, 01-steppers.cfg, control.cfg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]
2024-05-30 Use correct gcodes in PRINT_END (#10)
    Rewrite PRINT_END to use correct gcodes.
    Modify M141 to not error if chamber heater is not installed.
    Modify M107 to make changing fan names easier.
    Add beeping and retraction.
    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
    [control.cfg, macros.cfg]
2024-05-30 Fix bracketing (#11)
    Fix how fan string is created.
    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
    [macros.cfg]
2024-05-30 Orca fan numbering (#13)
    Closes #12
    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
    [macros.cfg]
2024-06-02 active chamber heater mod for X Smart 3
    [heater.cfg]
2024-06-02 Camera mount (#17)
    Add camera mount mod.
    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
    [camera-mount.stl]
2024-06-05 Update board image with hi-rez
    Image found in github:
    https://github.com/QIDITECH/QIDI_SMART3/issues/31
    https://github.com/fran6p/Qidi_X-Max3/blob/main/Images/Qidi-mks-skipr-pins.png
2024-06-06 In a working state
    [control.cfg, printer.cfg]
2024-06-06 Add adaptive mesh/purge
    [control.cfg, printer.cfg]
2024-06-06 Add description
    [control.cfg, fans.cfg]
2024-06-06 Set sane timeout
    [printer.cfg]
2024-06-06 Add idenifiers to messages
    [control.cfg]
2024-06-07 Prevent dupe calls?
    [control.cfg]
2024-06-07 Fix dupe PRINT_END, update homing_override
    [control.cfg]
2024-06-07 Add kamp file
    [Adaptive_Mesh.cfg]
2024-06-07 Adjust purge amounts for XS3
    [Adaptive_Mesh.cfg]
2024-06-07 All includes to the x-smart-3 dir
    [printer.cfg]
2024-06-07 Move configs to x-smart-3 dir
    [02-toolhead.cfg, xs3-kamp.cfg]
2024-06-07 Use TURN_OFF_HEATERS command
    [control.cfg]
2024-06-07 Add mcu temp sensor
    [temps.cfg]
2024-06-07 Whitespace cleanup
    [control.cfg]
2024-06-09 Rename and set correct mcus for temps
    [temps.cfg]
2024-06-09 Whitespace fix
    [02-toolhead.cfg]
2024-06-11 Switch to temp fan for pi
    [fans.cfg, temps.cfg]
2024-06-14 Update readme for thermistor mount
2024-06-14 Add chamber sensor
    [temps.cfg]
2024-06-14 Fan and temp names
    [fans.cfg, temps.cfg]
2024-06-19 Add stl files
    [fan-mount.stl, filter-base.stl, filter-cover.stl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]
2024-06-19 Repo setup
    [fan-mount.stl, filter-base.stl, filter-cover.stl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]
2024-06-29 Update z speeds
    [00-hardware.cfg]
2024-06-29 Use head soak countdown
    [control.cfg]
2024-06-29 Better console message
    [control.cfg]
2024-06-29 Start reorg, pids
    [00-hardware.cfg, printer.cfg, temps.cfg]
2024-06-29 Move PIDs for auto-saving
    [00-hardware.cfg, 000-printer.cfg, printer.cfg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]
2024-06-29 Latest calibrations
    [printer.cfg]
2024-07-15 Remove mcu fan, add filter fan
    [fans.cfg]
2024-07-15 Update M106
    [macros.cfg]
2024-07-15 Add host temp reporting
    [temps.cfg]
2024-09-25 Update nozzle preheat
    [control.cfg]
